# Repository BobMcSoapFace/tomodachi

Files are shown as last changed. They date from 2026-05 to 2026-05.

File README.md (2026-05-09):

# tomodachi

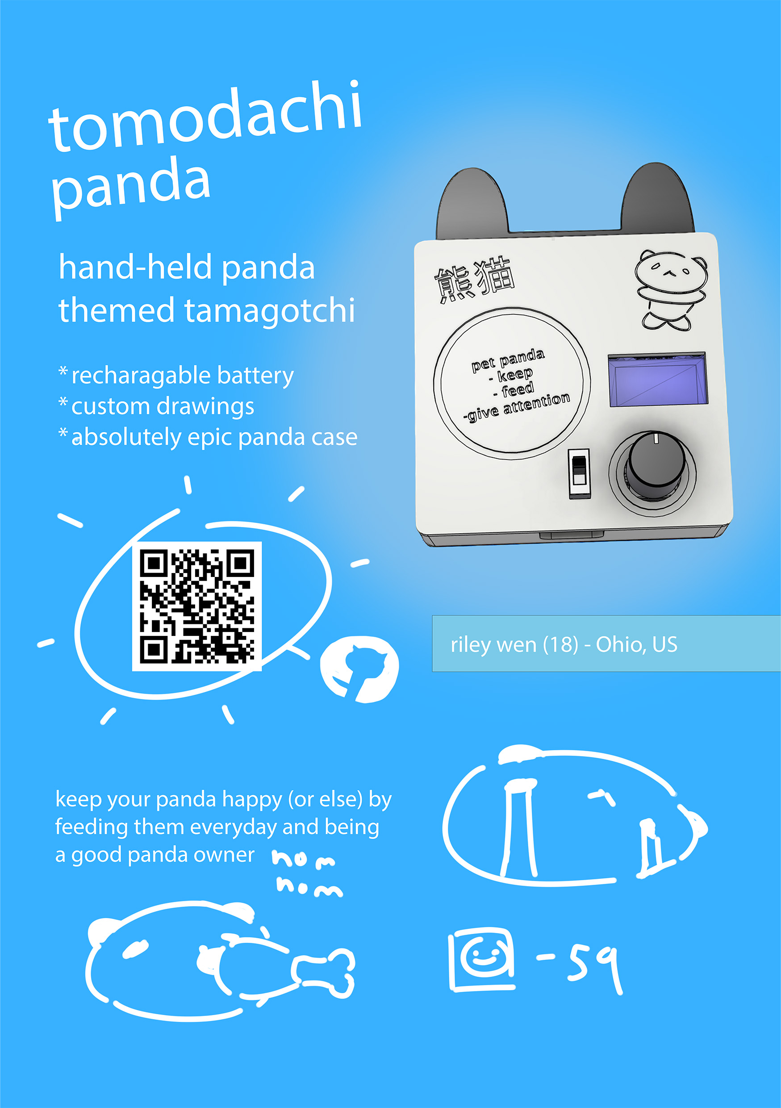
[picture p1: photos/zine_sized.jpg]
zine poster of the panda project


Tomodachi is a project to give you a heavily dependent and lazy panda to take care of, made because I need hardware and CAD design experience plus coding in firmware and also making panda themed gadgets is one of the coolest activities of all time

What the panda can do:
* Eat the food you give them (until they don't feel like it)
* Be head patted
* Perish

Features hand-drawn animations (more animations will come out once project is approed since I need the RTC to test more)

# materials

Name  | Quantity | Purchase link
------------- | ------------- | --------
ESP32C3  | 1 | [XIAO ESP32C3 DIP link](https://www.digikey.com/en/products/detail/seeed-technology-co-ltd/113991054/16652880)
DS3231 RTC | 1 | [DS3231 RTC link](https://www.ebay.com/itm/297741188722?chn=ps&google_free_listing_action=view_item)
Coin battery (for RTC if not included) | 1 | [Coin battery link](https://www.amazon.com/Murata-CR2032-Battery-Lithium-Coin/dp/B0B86LLWL8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)
0.96in SSD1306 (128x64) | 1 | [SSD1306 (128x64)](https://www.aliexpress.us/item/3256807708805773.html?src=google&gatewayAdapt=glo2usa)
TP4056 | 1 | [TP4056 link](https://www.aliexpress.us/item/3256810410652428.html?src=google&gatewayAdapt=glo2usa)
Shottky diodes | 2 | this was the cheapest & most appropriate I could find -> [Schottky diodes link](https://www.amazon.com/VKLSVAN-15SQ045-Schottky-Diodes-Blocking/dp/B0DQGSDM6K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)
KY-040 Rotary Encoder | 1 | [KY-040 Rotary encoder link](https://www.aliexpress.us/item/3256810332864684.html?src=google&gatewayAdapt=glo2usa)
SS12F44 Switch | 1 | [SS12F44 Switch link](https://www.aliexpress.us/item/3256804709322450.html?src=google&gatewayAdapt=glo2usa)
Battery 18650 3.7V | 1 | [18650 battery link](https://www.digikey.com/en/products/detail/tinycircuits/ASR00050/9808766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)
Wires | |

(the material links were used assuming the fallout team has amazon prime for free shipping)

# design
## PCB Schematic
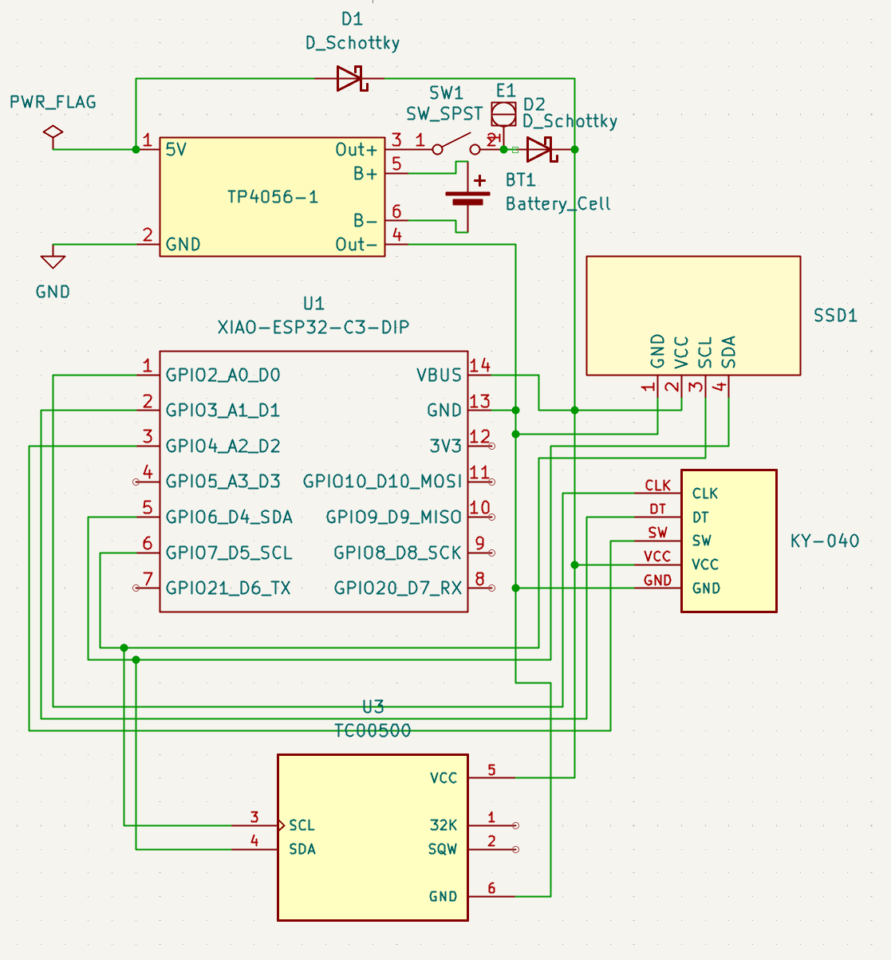
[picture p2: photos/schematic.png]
PCB schematic

^note that the part labeled E1 is because Kicad was mad I have the SS12F44 switch connected by wires instead of traces, please ignore
## PCB Footprint
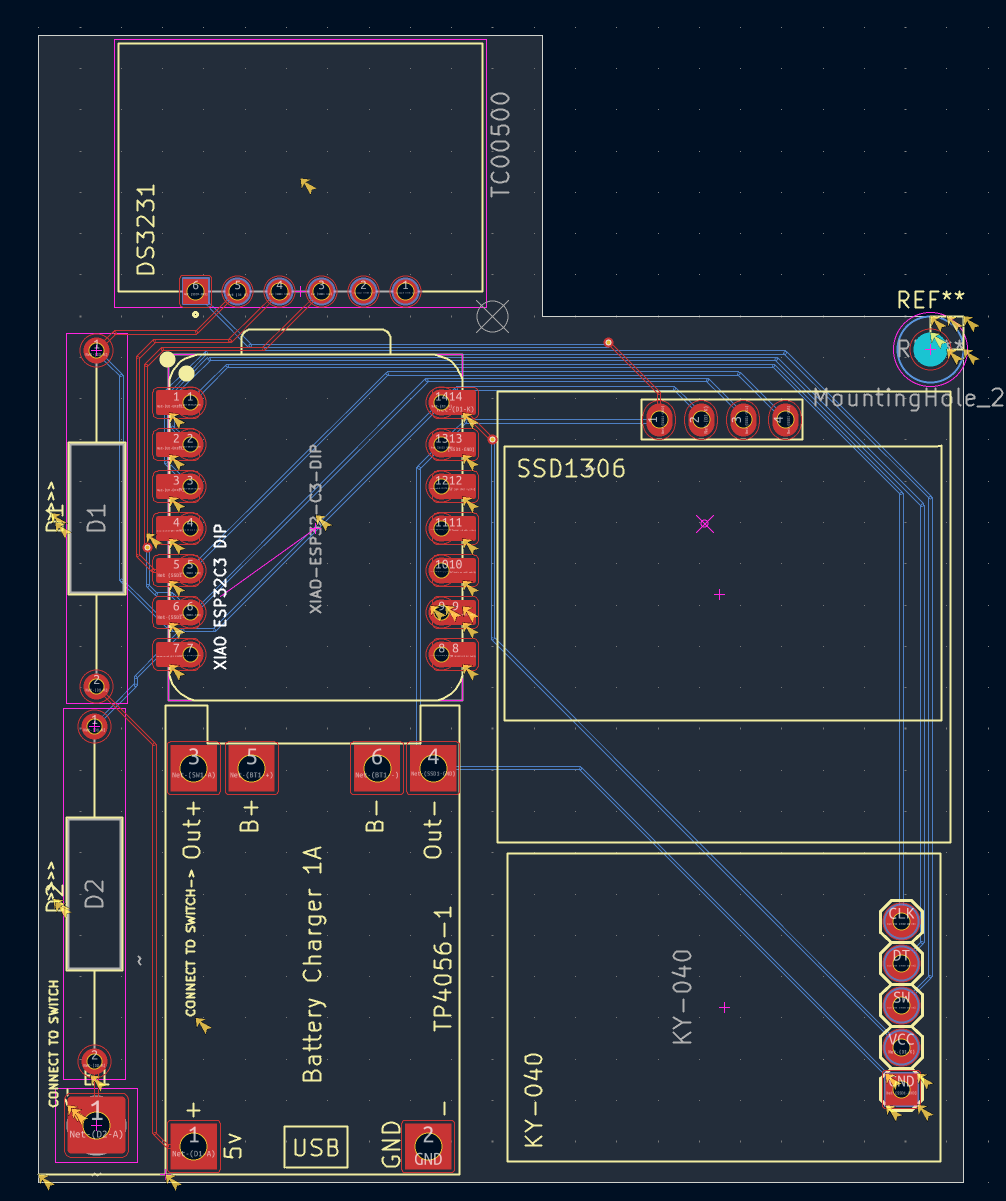
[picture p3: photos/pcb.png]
PCB footprint

## Case
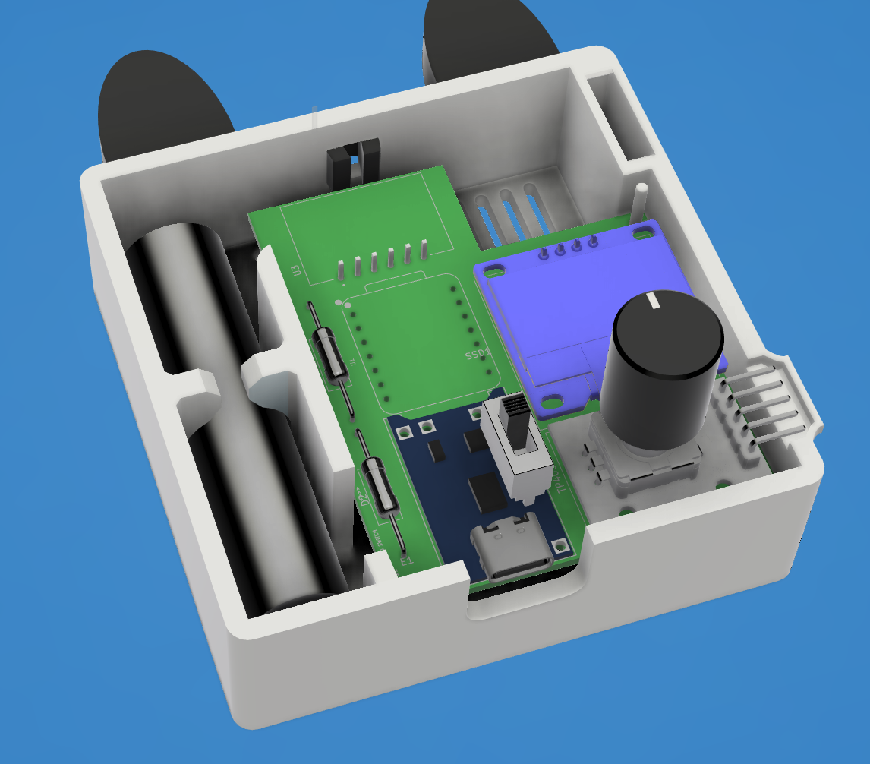
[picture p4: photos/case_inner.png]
Inside the 3D modeled case

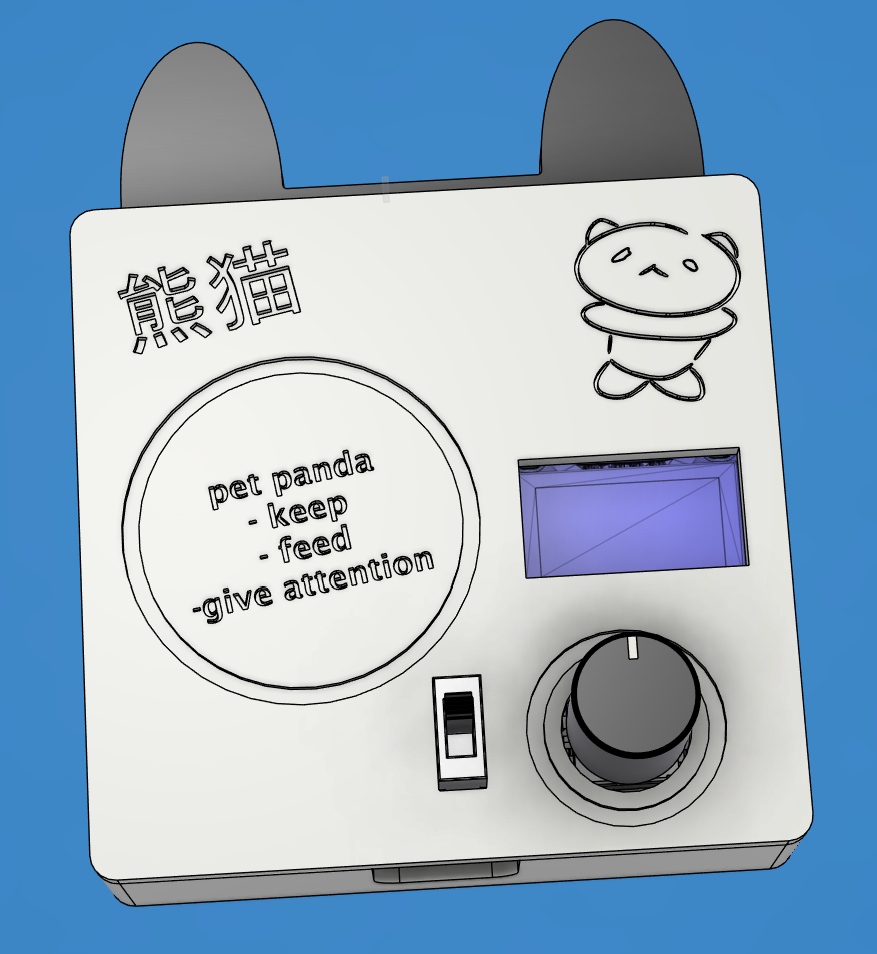
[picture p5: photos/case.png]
Outer 3D modeled case

# assembly
steps:
1. 3d print the case, case cover and panda ears
   - PLA is going to be used in this project but recommended to use a more stronger & less brittle filament for snap fits
2. Flash the firmware by using Arduino IDE:
   1. Download the firmware folder and place the firmware folder inside a dedicated folder
   2. Unzip the libraries.zip and place "libraries" folder in the dedicated folder (named exactly that)
   3. Go to Arduino IDE File > Preferences and set the library folder to libraries
   4. Connect the XIAO ESP32C3 DIP to the computer with a USB-C cable, select the port that pops up and set the board as a "XIAO_ESP32C3"
   5. Go to "tomodachi_sketch.ino" and compile and upload
3. Solder the components to the PCB
   - Use header pins to connect the throughholes on both the pcb and components for easier soldering (though tinning the holes will work too)
   - Make sure to insert the coin battery into the RTC after soldering (heat damage might hurt the battery)
4. Solder a wire from the bottom left corner pad marked "CONNECT TO SWITCH" (<ins>not</ins> the throughholes connected to the D2 schottky diode) to one end of the SS12F44 switch's three pins, and then solder a wire from the Out+ of the TP4056 component (also marked with "CONNECT TO SWITCH") to the middle pin on the SS12F44 switch's three pins
   - The SS12F44 connects the middle pin with one or the other of the three pins depending on where it is switched
   - Use a short length wire when soldering the two places, and wrap each connection in electrical tape to ensure no short circuits happen
   - For both of the mentioned throughholes on the PCB probably don't use header pins as it will be easier to solder a wire without them
5. Place the battery in the case first, then solder the wire from the battery's + end to the TP4056's 5V hole, and the battery's - end to the TP4056's GND hole (both located on the edge of the PCB)
6. Assemble case with cover and ears

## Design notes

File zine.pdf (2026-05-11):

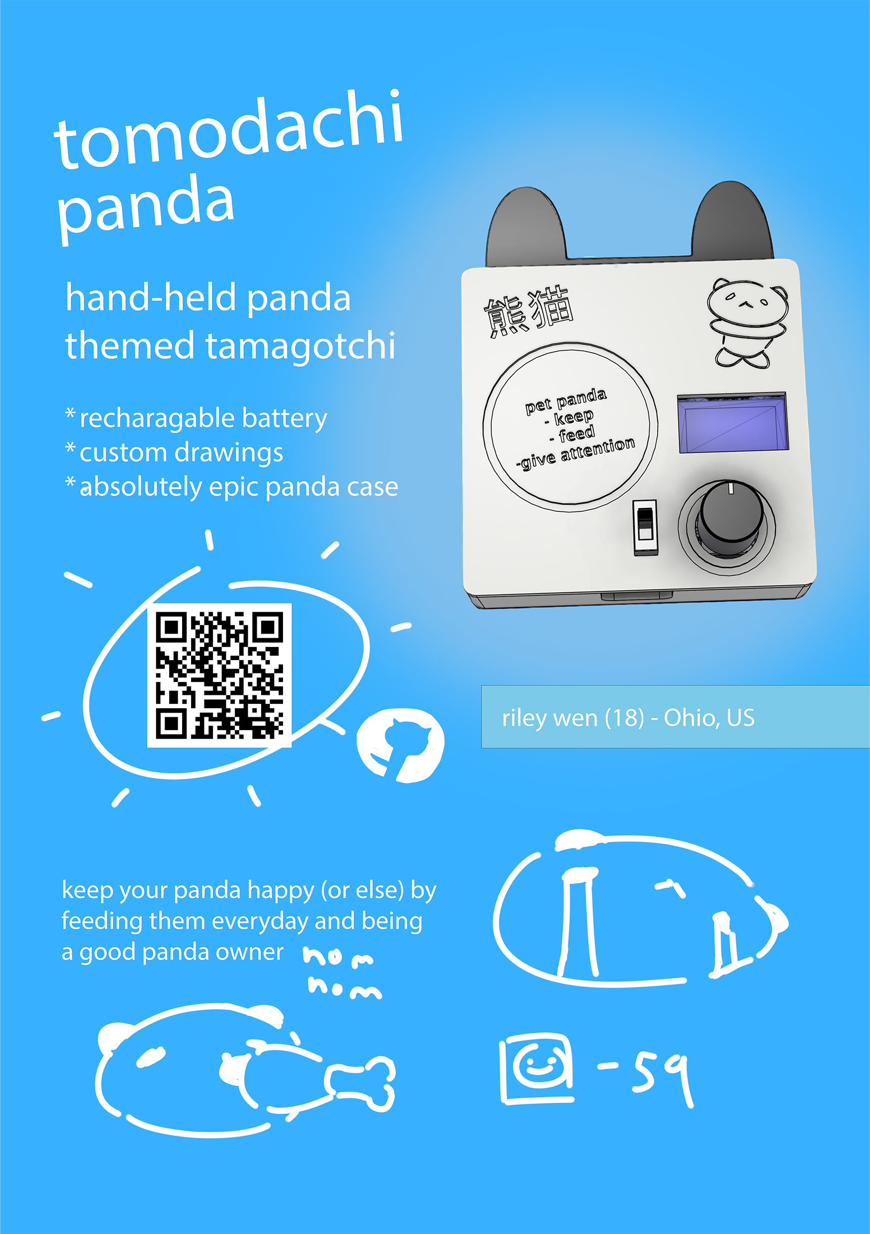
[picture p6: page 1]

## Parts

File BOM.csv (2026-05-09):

Name | Quantity | Links
ESP32C3 | 1 | https://www.digikey.com/en/products/detail/seeed-technology-co-ltd/113991054/16652880
DS3231 RTC | 1 | https://www.ebay.com/itm/297741188722?chn=ps&google_free_listing_action=view_item
Coin battery (for RTC if not included) | 1 | amazon.com/Murata-CR2032-Battery-Lithium-Coin/dp/B0B86LLWL8/ref=sr_1_2?crid=5N97OZSN6Z8H&dib=eyJ2IjoiMSJ9.F8PfWrmyizPbCG1gGso4Sn2BNfQ0eB1IYDHcMVNKymwzoMyjxj2rfjve1XwerShSBkc4a-dxVw_WuKlAkhaegxfFCFuhnR8R5kZjfYY0XphpTUnMTNZGNMzcZ4h64JS-bIkLakEKzOY6vGOThsG29ine8_IvoT9ieV70WUatbNnUaVEURMSSpseiIEaj0lkrKBS16BPGaSFWcJ-ryjQvp6fFocNM3I8KLXsGqz4SF25_1Fuxvltx6ggZdItXhQ_UIjJVnESPV-SKaemzGp7qIv84hWzi2OfmfkO0jIdj91Y.-Nvivpyu0MaXKH9qYVh21XHtwmFQd-MbeiVkGIs3xcA&dib_tag=se&keywords=cr2032+batteries&qid=1778205699&s=hpc&sprefix=CR2032+b%2Chpc%2C135&sr=1-2
0.96in SSD1306 (128x64) | 1 | https://www.aliexpress.us/item/3256807708805773.html?src=google&gatewayAdapt=glo2usa
TP4056 | 1 | https://www.aliexpress.us/item/3256810410652428.html?src=google&gatewayAdapt=glo2usa
Shottky diodes | 2 | https://www.amazon.com/VKLSVAN-15SQ045-Schottky-Diodes-Blocking/dp/B0DQGSDM6K?rnid=2470954011&rps=1
KY-040 Rotary Encoder | 1 | https://www.aliexpress.us/item/3256810332864684.html?src=google&gatewayAdapt=glo2usa
SS12F44 Switch | 1 | https://www.aliexpress.us/item/3256804709322450.html?src=google&gatewayAdapt=glo2usa
Battery 18650 3.7V | 1 | https://www.digikey.com/en/products/detail/tinycircuits/ASR00050/9808766?gclsrc=aw.ds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

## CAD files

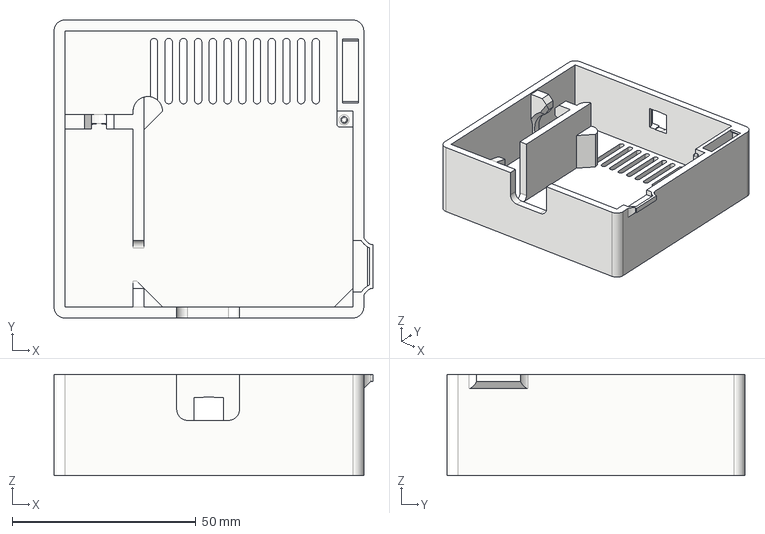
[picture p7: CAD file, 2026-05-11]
modelfiles/bottom_case.step
86.7 x 81.0 x 27.5 mm

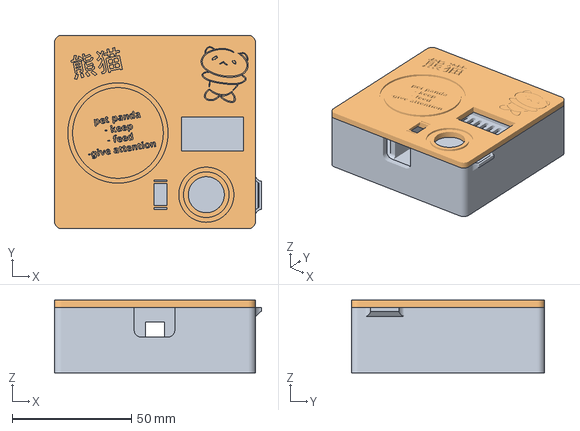
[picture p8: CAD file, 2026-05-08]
src/cad/model/tomodachi_printable.3mf
86.7 x 81.0 x 30.5 mm
case
cover

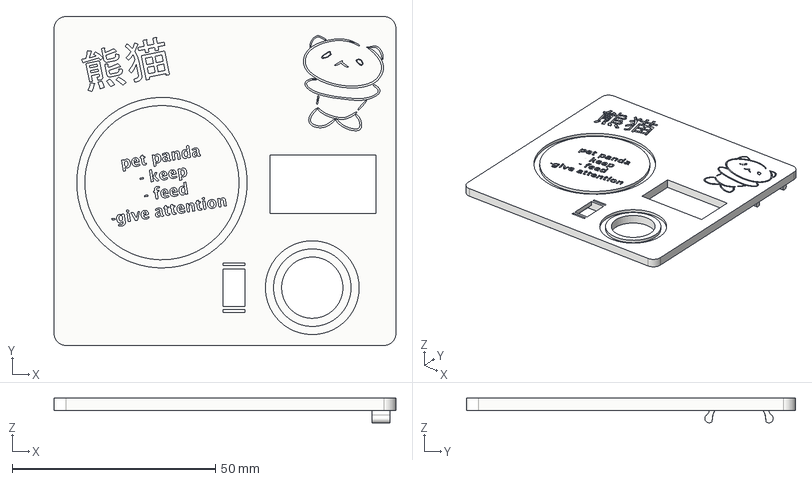
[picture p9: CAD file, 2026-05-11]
modelfiles/top_case.step
84.2 x 81.0 x 6.07 mm

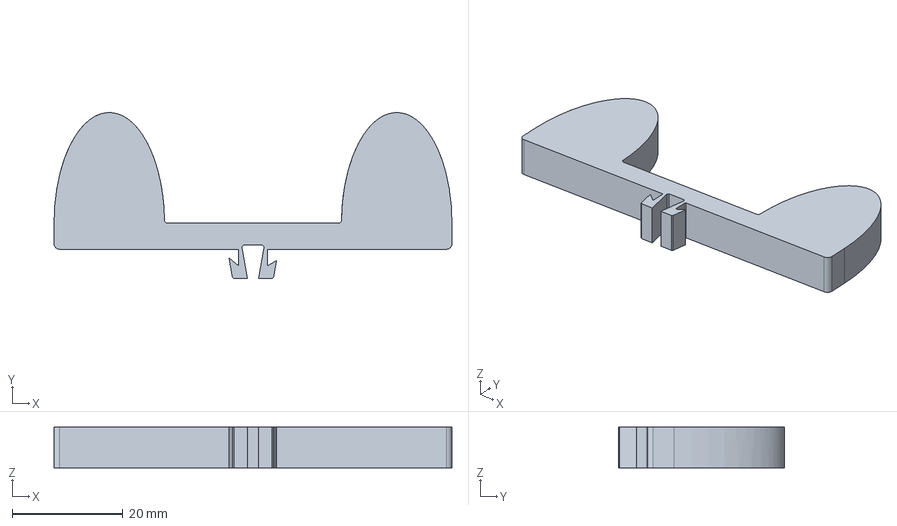
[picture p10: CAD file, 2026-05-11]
modelfiles/panda_ears.step
72.0 x 30.0 x 7.40 mm

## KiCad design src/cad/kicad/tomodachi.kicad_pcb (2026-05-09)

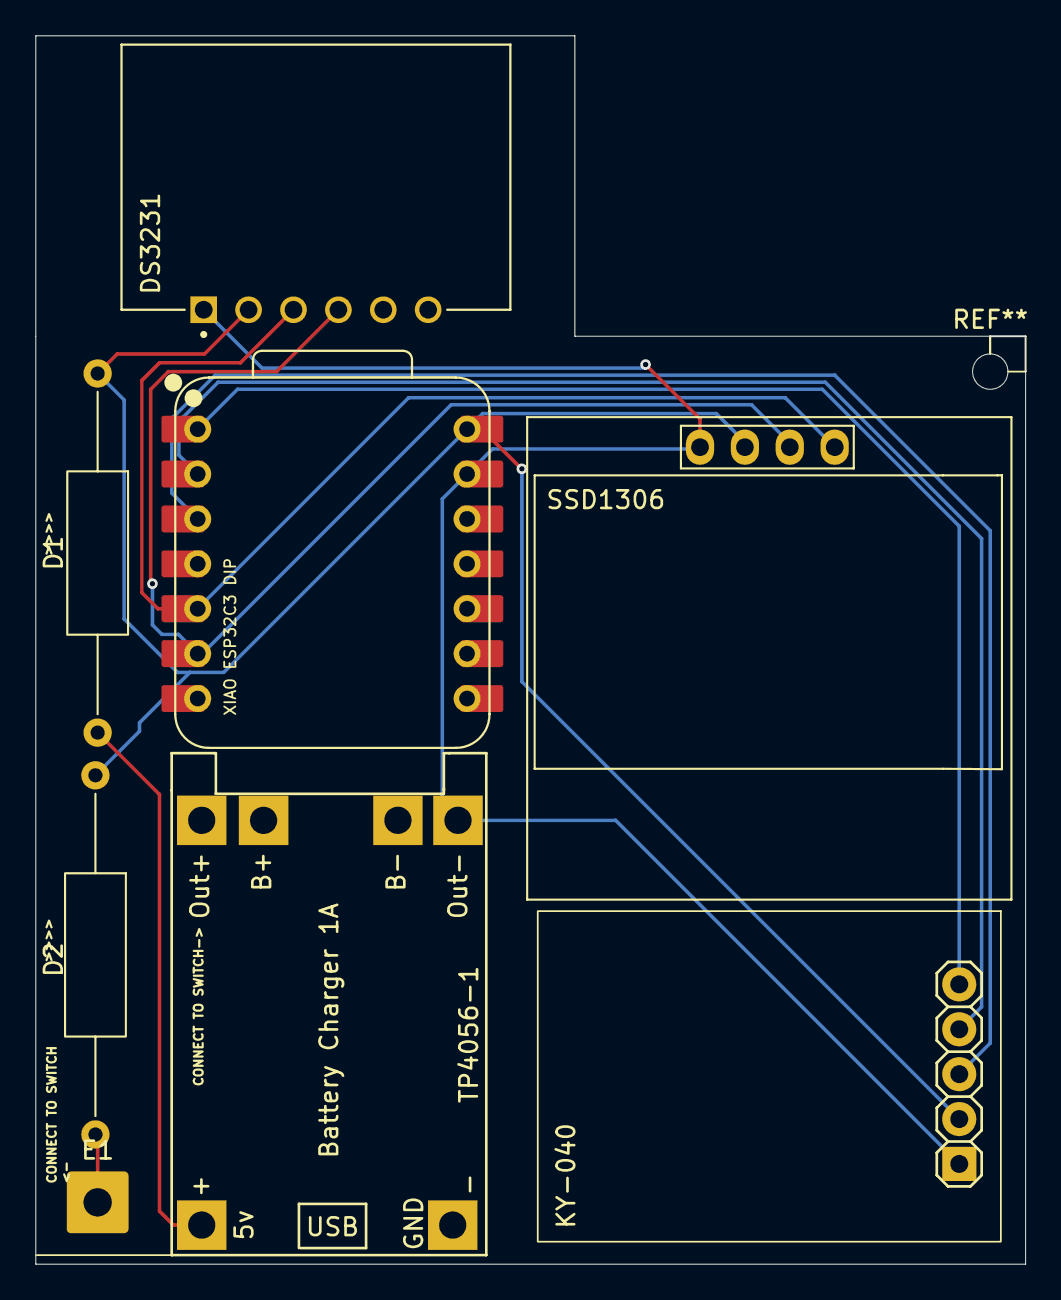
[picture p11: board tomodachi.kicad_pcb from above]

Board: 2 copper layers, 56.0 x 69.5 mm, 8 parts (0 on the bottom side), 9 nets.

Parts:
D1, D2: D_Schottky; R_Axial_DIN0309_L9.0mm_D3.2mm_P20.32mm_Horizontal
DS3231: TC00500; MODULE_TC00500
E1: SolderWire-0.75sqmm_1x01_D1.25mm_OD3.5mm
KY-040: KY-040; KY-040-PORT
SSD1306: SSD1306128x64OLED
TP4056-1: TP4056-18650
XIAO ESP32C3 DIP: XIAO-ESP32-C3-DIP

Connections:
unnamed: D1.2 (A), TP4056-1.1 (5V)
unnamed: D1.1 (K), D2.1 (K), DS3231.5 (VCC), KY-040.VCC, SSD1306.2 (VCC), XIAO ESP32C3 DIP.14 (VBUS)
unnamed: D2.2 (A), E1.1
unnamed: DS3231.6 (GND), KY-040.GND, SSD1306.1 (GND), TP4056-1.4 (Out-), XIAO ESP32C3 DIP.13 (GND)
unnamed: DS3231.3 (SCL), SSD1306.3 (SCL), XIAO ESP32C3 DIP.6 (GPIO7_D5_SCL)
unnamed: DS3231.4 (SDA), SSD1306.4 (SDA), XIAO ESP32C3 DIP.5 (GPIO6_D4_SDA)
unnamed: KY-040.CLK, XIAO ESP32C3 DIP.1 (GPIO2_A0_D0)
unnamed: KY-040.DT, XIAO ESP32C3 DIP.2 (GPIO3_A1_D1)
unnamed: KY-040.SW, XIAO ESP32C3 DIP.3 (GPIO4_A2_D2)

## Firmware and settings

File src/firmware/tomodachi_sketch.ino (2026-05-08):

#include <Wire.h> // i2c
#include <KY040.h> //rotary encoder
#include <RTClib.h> //real time
#include <Preferences.h>

//display
#include <Adafruit_GFX.h>
#include <Adafruit_SSD1306.h>
#include "animations.h"

//---------------
//animations

// structure to hold animation state information (currentTick) and animation info
// * const bool* anim - bool pointer to first element of the animation
// * uint8_t fps - frames per second
// * uint8_t width - width of animation in pixels
// * uint8_t height - height of animation in pixels
// * bool loop - whether the animation should return to the first frame once done
// * int currentTick - current time of the animation playing (always set to zero)
struct Animation {
  const bool* anim;
  uint8_t fps;
  uint8_t frames;
  uint8_t width;
  uint8_t height;
  bool loop;
  int currentTick = 0; //milliseconds, tracks current time
};
struct Animation pandaAnimation = {
  &(PANDAIDLE[0][0][0]),
  3, //fps
  2, //frames
  48 , //width
  48, //height
  true, //loop
  0
};
struct Animation foodIcon = {
  &(FOODICON[0][0][0]),
  1,
  1,
  16,
  16,
  false,
  0
};
struct Animation happinessIcon = {
  &(HAPPINESSICON[0][0][0]),
  1,
  1,
  16,
  16,
  false,
  0
};
struct Animation handIcon = {
  &(HANDICON[0][0][0]),
  1,
  1,
  15,
  15,
  false,
  0
};
struct Animation foodItem = {
  &(FOODITEM[0][0][0]),
  1,
  1,
  32,
  32,
  false,
  0
};
struct Animation skullFrame = {
  &(SKULLFRAME[0][0][0]),
  1,
  1,
  32,
  32,
  false,
  0
};

//---------------

#define TICK_SPEED 50

#define ROTARY_CLK_PIN 0
#define ROTARY_DT_PIN 1
#define ROTARY_SW_PIN 2

#define SDA_PIN 4
#define SCL_PIN 5
#define SSD1306_ADDR 0x3C
#define RTC_ADDR 0x68
#define NVM_NAMESPACE "nvm"

//screen

#define SCREEN_WIDTH 128 // OLED display width, in pixels
#define SCREEN_HEIGHT 64 // OLED display height, in pixels
#define OLED_RESET     -1 // Reset pin # (or -1 if sharing Arduino reset pin)
Adafruit_SSD1306 display(SCREEN_WIDTH, SCREEN_HEIGHT, &Wire, OLED_RESET);
int curScreen = 0;

bool doHighlight = true;
void selectHighlight(int x, int total){
  if(selectv()%total==x && doHighlight) display.setTextColor(BLACK, WHITE); else display.setTextColor(WHITE);
}
void playAnimation(
  Animation &anim,
  int x,
  int y
){
  playAnimation(anim, x, y, true);
}
void playFlippedAnimation(
  Animation &anim,
  int x,
  int y
) {
  bool finished = anim.currentTick >= (int)((1000.0/anim.fps)*(anim.frames));
  uint8_t frame = min((int)(anim.currentTick/(1000.0/anim.fps)), anim.frames-1);
  for(int i = 0; i < anim.height; i++){
    for(int j = 0; j < anim.width; j++){
      display.drawPixel(x+j, y+i, anim.anim[anim.frames*anim.width*anim.height - 1 - (frame*anim.width*anim.height + anim.width*i + j)]);
    }
  }
  if(anim.frames <= 1) return;
  
  if(!finished) {
    anim.currentTick += TICK_SPEED;
  } else if(anim.loop){
    anim.currentTick = 0;
  }
}
void playAnimation(
  Animation &anim,
  int x,
  int y,
  bool overwrite
){
  bool finished = anim.currentTick >= (int)((1000.0/anim.fps)*(anim.frames));
  uint8_t frame = min((int)(anim.currentTick/(1000.0/anim.fps)), anim.frames-1);
  for(int i = 0; i < anim.height; i++){
    for(int j = 0; j < anim.width; j++){
      if(!overwrite && !anim.anim[frame*anim.width*anim.height + anim.width*i + j]){
        continue;
      }
      display.drawPixel(x+j, y+i, anim.anim[frame*anim.width*anim.height + anim.width*i + j]);
    }
  }
  if(anim.frames <= 1) return;
  
  if(!finished) {
    anim.currentTick += TICK_SPEED;
  } else if(anim.loop){
    anim.currentTick = 0;
  }
}
//rtc -----
RTC_DS3231 rtc;
const int monthDays[12] = {31, 30, 29, 30, 31, 30, 31, 31, 30, 31, 30, 31}; // i literally hate this calendar

//rotary encoder -----
volatile int select_x=0;
KY040 g_rotaryEncoder(ROTARY_CLK_PIN,ROTARY_DT_PIN);

// ISR to handle the interrupts for CLK and DT
void ISR_rotaryEncoder() {
  // Process pin states for CLK and DT
  switch (g_rotaryEncoder.getRotation()) {   
    case KY040::CLOCKWISE:
      select_x++;
      break;
    case KY040::COUNTERCLOCKWISE:
      select_x--;
      break;
  }
}
bool isPushed(){
  return digitalRead(ROTARY_SW_PIN) == 0;
}
bool _wasUp = true;
bool isClicked(){
  bool pushed = isPushed();
  if(_wasUp && pushed){
    _wasUp = false;
    return true;
  } else if(!_wasUp && !pushed){
    _wasUp = true;
  }
  return false;
}
int vOffset = 0;
void resetv() {
  vOffset = selectv();
}
void resetv(int to){
  vOffset = selectv()-to;
}
int selectv(){
  return (select_x-vOffset) < 0 ? 20+((select_x-vOffset)%20) : (select_x-vOffset)%20;
}
// non-volatile memory
#define INITIALIZED_KEY "initialized"
#define HUNGER_KEY "HUNGER"
#define HAPPINESS_KEY "HAPPINESS"
#define LASTATE_KEY "LASTATE"
#define DIED_KEY "DIED"
#define LASTCHANGE_KEY "LASTBOOT"
#define TIMEADJUSTED "TIMEADJUSTED"
const int MAX_HAPPINESS = 100;
const int MAX_HUNGER = 100;

Preferences nvm;

//---------------------
const int MAX_INIT_TRIES = 20;
const int HUNGER_DECREASE_INTERVAL = 1000; //every 1000 seconds panda hunger goes down by 1, in an hour loses 3.6 hunger
const int HAPPINESS_DECREASE_INTERVAL = 1200; //every 1200 seconds panda hunger goes down by 1, in an hour loses 3 hunger

int hunger = 100;
int happiness = 100;
long lastAte = -1;
bool died = false;

long lastChange = -1; //epoch milliseconds (from 1970)
DateTime currentBoot;

void initMemory(){
  if(!nvm.getBool(INITIALIZED_KEY, false)){
    Serial.println("Initializing default parameters");
    nvm.putInt(HUNGER_KEY, 100);
    nvm.putInt(HAPPINESS_KEY, 100);
    nvm.putLong(LASTATE_KEY, -1);
    nvm.putBool(DIED_KEY, false);
    nvm.putLong(LASTCHANGE_KEY, -1);
    nvm.putBool(INITIALIZED_KEY, true);
  } else {
    happiness = nvm.getInt(HAPPINESS_KEY);
    hunger = nvm.getInt(HUNGER_KEY);
    lastAte = nvm.getLong(LASTATE_KEY);
    lastChange = nvm.getLong(LASTCHANGE_KEY);
    died = nvm.getBool(DIED_KEY); 
  }
}
void pandaProcesses(){
  long curTime = (long)(rtc.now().unixtime());
  if(lastChange > -1 && curTime > lastChange){
    if(curTime - lastChange > min(HUNGER_DECREASE_INTERVAL, HAPPINESS_DECREASE_INTERVAL) && !died){
      happiness -= (int)((curTime - lastChange)/HAPPINESS_DECREASE_INTERVAL);
      hunger -= (int)((curTime - lastChange)/HUNGER_DECREASE_INTERVAL);

      lastChange = curTime;
      nvm.putLong(LASTCHANGE_KEY, curTime);
    }
  }
  if((hunger >= 200 || hunger <= 0) && !died){
    died = true; // rip
    saveStatus();
  }
}
void saveStatus(){
  nvm.putInt(HUNGER_KEY, hunger);
  nvm.putInt(HAPPINESS_KEY, happiness);
  nvm.putBool(DIED_KEY, died);
}

//----------------------------------------
void setup() {
  Serial.begin(9600);
  Wire.begin(20, 21);
  Serial.println("Initializing");
  uint8_t displayTries = 0;
  uint8_t rtcTries = 0;
  uint8_t nvmTries = 0;
  while(!display.begin(SSD1306_SWITCHCAPVCC, 0x3C)) { 
    Serial.println(F("SSD1306 allocation failed"));
    delay(10);
  }
  while(!rtc.begin(&Wire)){
    Serial.println("Could not initialize rtc, retrying...");
    if(rtcTries > MAX_INIT_TRIES){
      display.clearDisplay();
      display.setCursor(0,0);
      display.write("RTC FAILURE");
      display.display();
      while(1) delay(100);
    }
    rtcTries++;
    delay(10);
  }
  while(!nvm.begin(NVM_NAMESPACE, false)){
    Serial.println("Could not initialize nvm, retrying...");
    if(nvmTries > MAX_INIT_TRIES){
      display.clearDisplay();
      display.setCursor(0,0);
      display.write("NVM (NON-VOLATILE MEMORY) FAILURE");
      display.display();
      while(1) delay(100);
    }
    nvmTries++;
    delay(10);
  }

  attachInterrupt(digitalPinToInterrupt(ROTARY_CLK_PIN), ISR_rotaryEncoder, CHANGE);
  attachInterrupt(digitalPinToInterrupt(ROTARY_DT_PIN), ISR_rotaryEncoder, CHANGE);
  pinMode(ROTARY_SW_PIN, INPUT);
  Serial.println("Passed pin initialization");
  initMemory();
  Serial.println("Passed memory initialization");
  if(lastChange >= -1){
    DateTime dtnow = rtc.now();
    currentBoot = dtnow;
    nvm.putLong(LASTCHANGE_KEY, dtnow.unixtime());
  }
  if(nvm.getBool(TIMEADJUSTED, false)){
    curScreen = 1;
  }
}
//----------------------------------------
void loop() {
  display.clearDisplay();

  cli();
  sei();
  switch (curScreen) {
    case 0:
      drawTimeAdjustScreen();
      break;
    case 1:
      drawHomeScreen();
      pandaProcesses();
      break;
    default:
      display.setTextColor(WHITE);
      display.setCursor(0, SCREEN_HEIGHT/2-4);
      display.write("INVALID SCREEN");
      display.display();
  }
  //tick speed; determines screen update frequency & check intervals for input and durations
  delay(TICK_SPEED);
}

//----------------------------------------
void drawHomeScreen(){
  display.clearDisplay();
  display.setTextColor(WHITE);
  if(died)
  playAnimation(
    skullFrame, 
    (SCREEN_WIDTH-skullFrame.width)/2,
    (SCREEN_HEIGHT-skullFrame.height)/2
  );
  else if(happiness > 0)
  playAnimation(
    pandaAnimation, 
    (SCREEN_WIDTH-pandaAnimation.width)/2,
    (SCREEN_HEIGHT-pandaAnimation.height)/2
  );
  else
  playFlippedAnimation(
    pandaAnimation, 
    (SCREEN_WIDTH-pandaAnimation.width)/2,
    (SCREEN_HEIGHT-pandaAnimation.height)/2
  );

  display.setTextSize(1);
  playAnimation(
    foodIcon, 
    2, 
    (SCREEN_HEIGHT-foodIcon.height-2)
  );
  display.setCursor(2+foodIcon.width+2, (SCREEN_HEIGHT)-2-(foodIcon.height)/2-4);
  if(selectv()%5==1) display.setTextColor(BLACK, WHITE); else display.setTextColor(WHITE);
  display.write(String(hunger).c_str());

  playAnimation(
    happinessIcon, 
    (SCREEN_WIDTH-happinessIcon.width)/2 - 8, 
    (SCREEN_HEIGHT-happinessIcon.height-2)
  );
  display.setCursor((SCREEN_WIDTH + happinessIcon.width)/2 - 6, (SCREEN_HEIGHT)-2-(happinessIcon.height)/2-4);
  if(selectv()%5==2) display.setTextColor(BLACK, WHITE); else display.setTextColor(WHITE);
  display.write(String(happiness).c_str());

  if(selectv()%5==3){
    playAnimation(
      handIcon,
      (SCREEN_WIDTH-handIcon.width)/2,
      5
    );
  }
  if(selectv()%5==4){
    playAnimation(
      foodItem,
      (SCREEN_WIDTH-handIcon.width)/2 - 40,
      5,
      false
    );
  }

  display.drawPixel(0, SCREEN_HEIGHT-1, WHITE);
  display.drawPixel(SCREEN_WIDTH-1, SCREEN_HEIGHT-1, WHITE);
  display.drawPixel((SCREEN_WIDTH)/2, SCREEN_HEIGHT-1, WHITE);
  display.drawPixel((SCREEN_WIDTH)/2+1, SCREEN_HEIGHT-1, WHITE);
  display.display();

  if(isClicked()){
    switch(selectv()%5){
      case 1:
        hunger++;
        saveStatus();
        break;
      case 2:
        saveStatus();
        break;
      case 3:
        happiness++;
        saveStatus();
        break;
      case 4:
        hunger+=10;
        if(hunger > MAX_HUNGER+1){
          happiness-=5;
        }
        saveStatus();
        break;
      default:
        break;
    }
  }
}
void drawTimeAdjustScreen(){
  //static vars;
  static int year = 2026;
  static int month = 1;
  static int day = 1;
  static int hour = 12;
  static int minute = 0;
  static int timeSelected = -1;
  static DateTime dt;
  static int prev_x = select_x;
  //-----

  uint16_t t_width, t_height; 
  int16_t _x, _y;

  int trigoffset;
  bool draw = true;
  display.clearDisplay();

  //draw hours
  display.setTextColor(WHITE);
  display.setTextSize(2);
  display.getTextBounds("00:00", 0, 0, &_x, &_y, &t_width, &t_height);
  display.setCursor((SCREEN_WIDTH-t_width)/2, (SCREEN_HEIGHT-t_height)/2-8);

  selectHighlight(1, 7);
  display.write(String(hour).c_str());
  display.setTextColor(WHITE);
  display.write(":");
  selectHighlight(2, 7);
  display.write(String(String(minute < 10 ? "0" : "")+String(minute)).c_str());
  display.setTextColor(WHITE);
  
  display.getTextBounds("00:00:0000", 0, 0, &_x, &_y, &t_width, &t_height);
  display.setCursor((SCREEN_WIDTH-t_width)/2, (SCREEN_HEIGHT-t_height)/2 + 8);
  selectHighlight(3, 7);
  display.write(String(String(month < 10 ? "0" : "")+String(month)).c_str());
  display.setTextColor(WHITE);
  display.write("/");
  selectHighlight(4, 7);
  display.write(String(String(day < 10 ? "0" : "")+String(day)).c_str());
  display.setTextColor(WHITE);
  display.write("/");
  selectHighlight(5, 7);
  display.write(String(year).c_str());

  display.setTextSize(1);
  selectHighlight(6, 7);
  display.getTextBounds("Set current time", 0, 0, &_x, &_y, &t_width, &t_height);
  display.setCursor((SCREEN_WIDTH-t_width)/2, SCREEN_HEIGHT-t_height); 
  if(!draw) display.setTextColor(BLACK, WHITE);
  display.write("Set current time");
  display.display();

  int inc = select_x > prev_x ? 1 : select_x < prev_x ? -1 : 0;
  if(prev_x != select_x){
    prev_x = select_x;
  }
  switch(timeSelected){
    case 1:
      hour+=inc;
      break;
    case 2:
      minute+=inc;
      break;
    case 3:
      month+=inc;
      break;
    case 4:
      day+=inc;
      break;
    case 5:
      year+=inc;
      break;
    default:
      break;
  }

  //bound checking
  if(hour >= 24){
    hour = 0;
  } else if(hour < 0){
    hour = 23;
  }
  if(minute >= 60){
    minute = 0;
    hour++;
  } else if(minute < 0){
    hour--;
    minute=59;
  }
  if(month > 12){
    month = 1;
    year++;
  } else if(month < 1){
    month = 12;
    year--;
  }
  //leap year handling (terrible)
  if(year%4!=0){
    if(month == 3 && day < 1){
      month = 2;
      day = 28;
    } else if(month == 2 && day > 28){
      month = 3;
      day = 1;
    }
  }
  //---
  //pleaswe donmt make me check for overflow again
  if(day > monthDays[month-1]){
    month++;
    day = 1;
  } else if(day < 1){
    month--;
    day = monthDays[month-1];
  }

  Serial.println(select_x);
  Serial.println(vOffset);
  Serial.println(selectv());
  Serial.println(selectv()%7);
  Serial.println(timeSelected);

  //sw func
  if(isClicked()){
    if(timeSelected >= 0){
      doHighlight = true;
      resetv(timeSelected);
      timeSelected = -1;
    } else if(selectv()%7 != 0 && selectv()%7 != 6) {
      doHighlight = false;
      timeSelected = selectv()%7;
    } else if(selectv()%7 == 6) {
      curScreen = 1;
      resetv();
      // set rtc stuff here
      const DateTime newDt = DateTime(
          year,
          month,
          day,
          hour,
          minute
      );
      if(nvm.getLong(LASTCHANGE_KEY, -1) == -1){
        nvm.putLong(LASTCHANGE_KEY, newDt.unixtime());
        currentBoot = newDt;
      }
      rtc.adjust(newDt);
      nvm.putBool(TIMEADJUSTED, true);
    }
  }
}

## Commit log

2026-05-09 fixed PCB & added BOM and 3D files
    [.step, .stl, BOM.csv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]
2026-05-09 updated BOM
    [BOM.csv]
2026-05-11 fixed missing zine and cad files
    [bottom_case.step, panda_ears.step, top_case.step]
